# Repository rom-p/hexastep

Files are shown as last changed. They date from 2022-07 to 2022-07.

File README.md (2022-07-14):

6-axis stepper driver for **Raspberry Pi Pico**

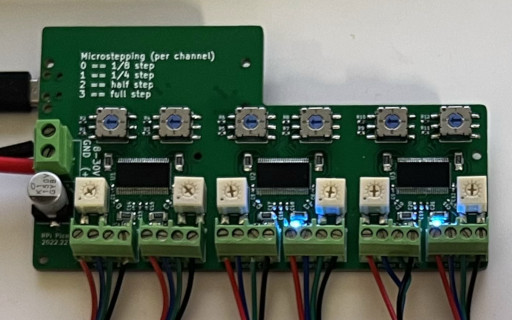
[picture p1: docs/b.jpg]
view


The **Raspberry Pi Pico** is on the back side of this board

# Prerequisites
* KiCad 6.0+
* load symbols and footprints.  The schematic and PCB depend on the library located in `/libs`, which needs to be added before opening the schematics/pcb in KiCad:
  * symbols: **KiCad** -> **Preferences** -> **Manage Symbol Libraries...**,
  * footprints: **KiCad** -> **Preferences** -> **Manage Footprint Libraries...**
* PCB manufacturing: any manufacturer capable of 4-layer and 0.4mm vias -- pretty much any PCB shop

# Schematic
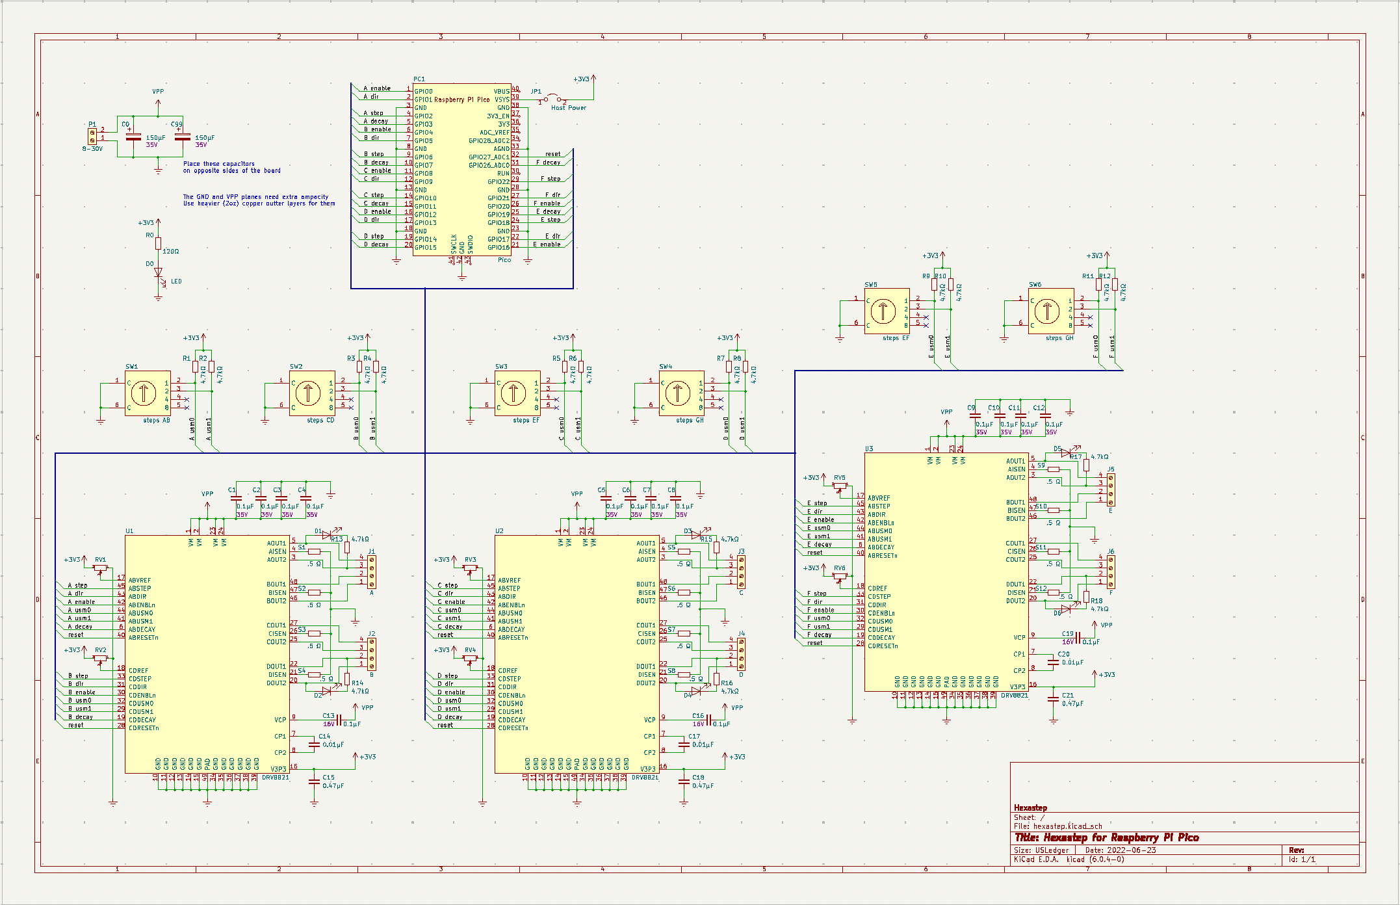
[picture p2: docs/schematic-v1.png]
schematic
  (also in [PDF](docs/schematic-v1.pdf))

# Parts
https://octopart.com/bom-tool/PoB5E81H

# Footnotes
the photo at the top of this page is of a previous version of the board.  The current version has:
  * a slightly different layout
  * a power LED
  * a jumper for powering R-Pi Pico
  * better filtering.

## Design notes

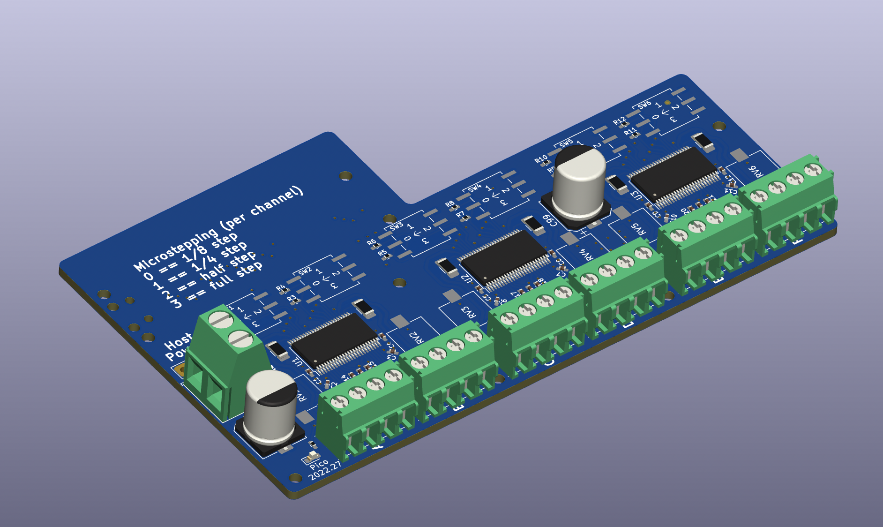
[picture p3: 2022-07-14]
docs/kicad-board-view-v1.png

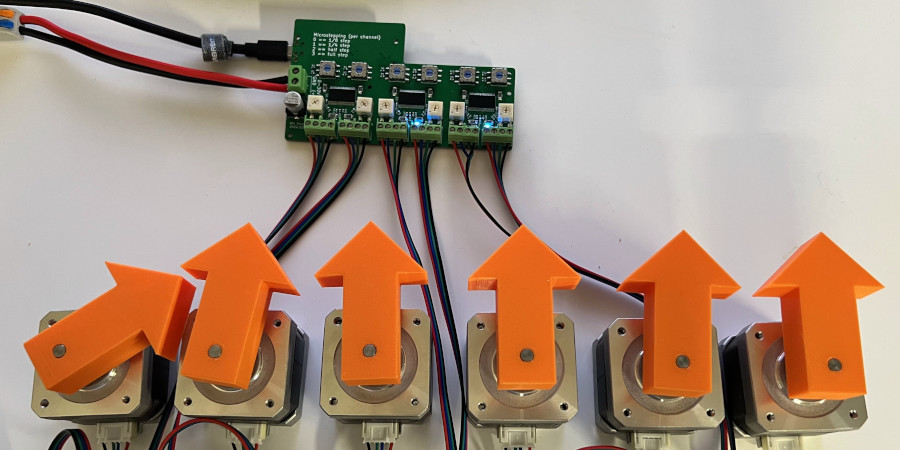
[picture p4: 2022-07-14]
docs/m.jpg

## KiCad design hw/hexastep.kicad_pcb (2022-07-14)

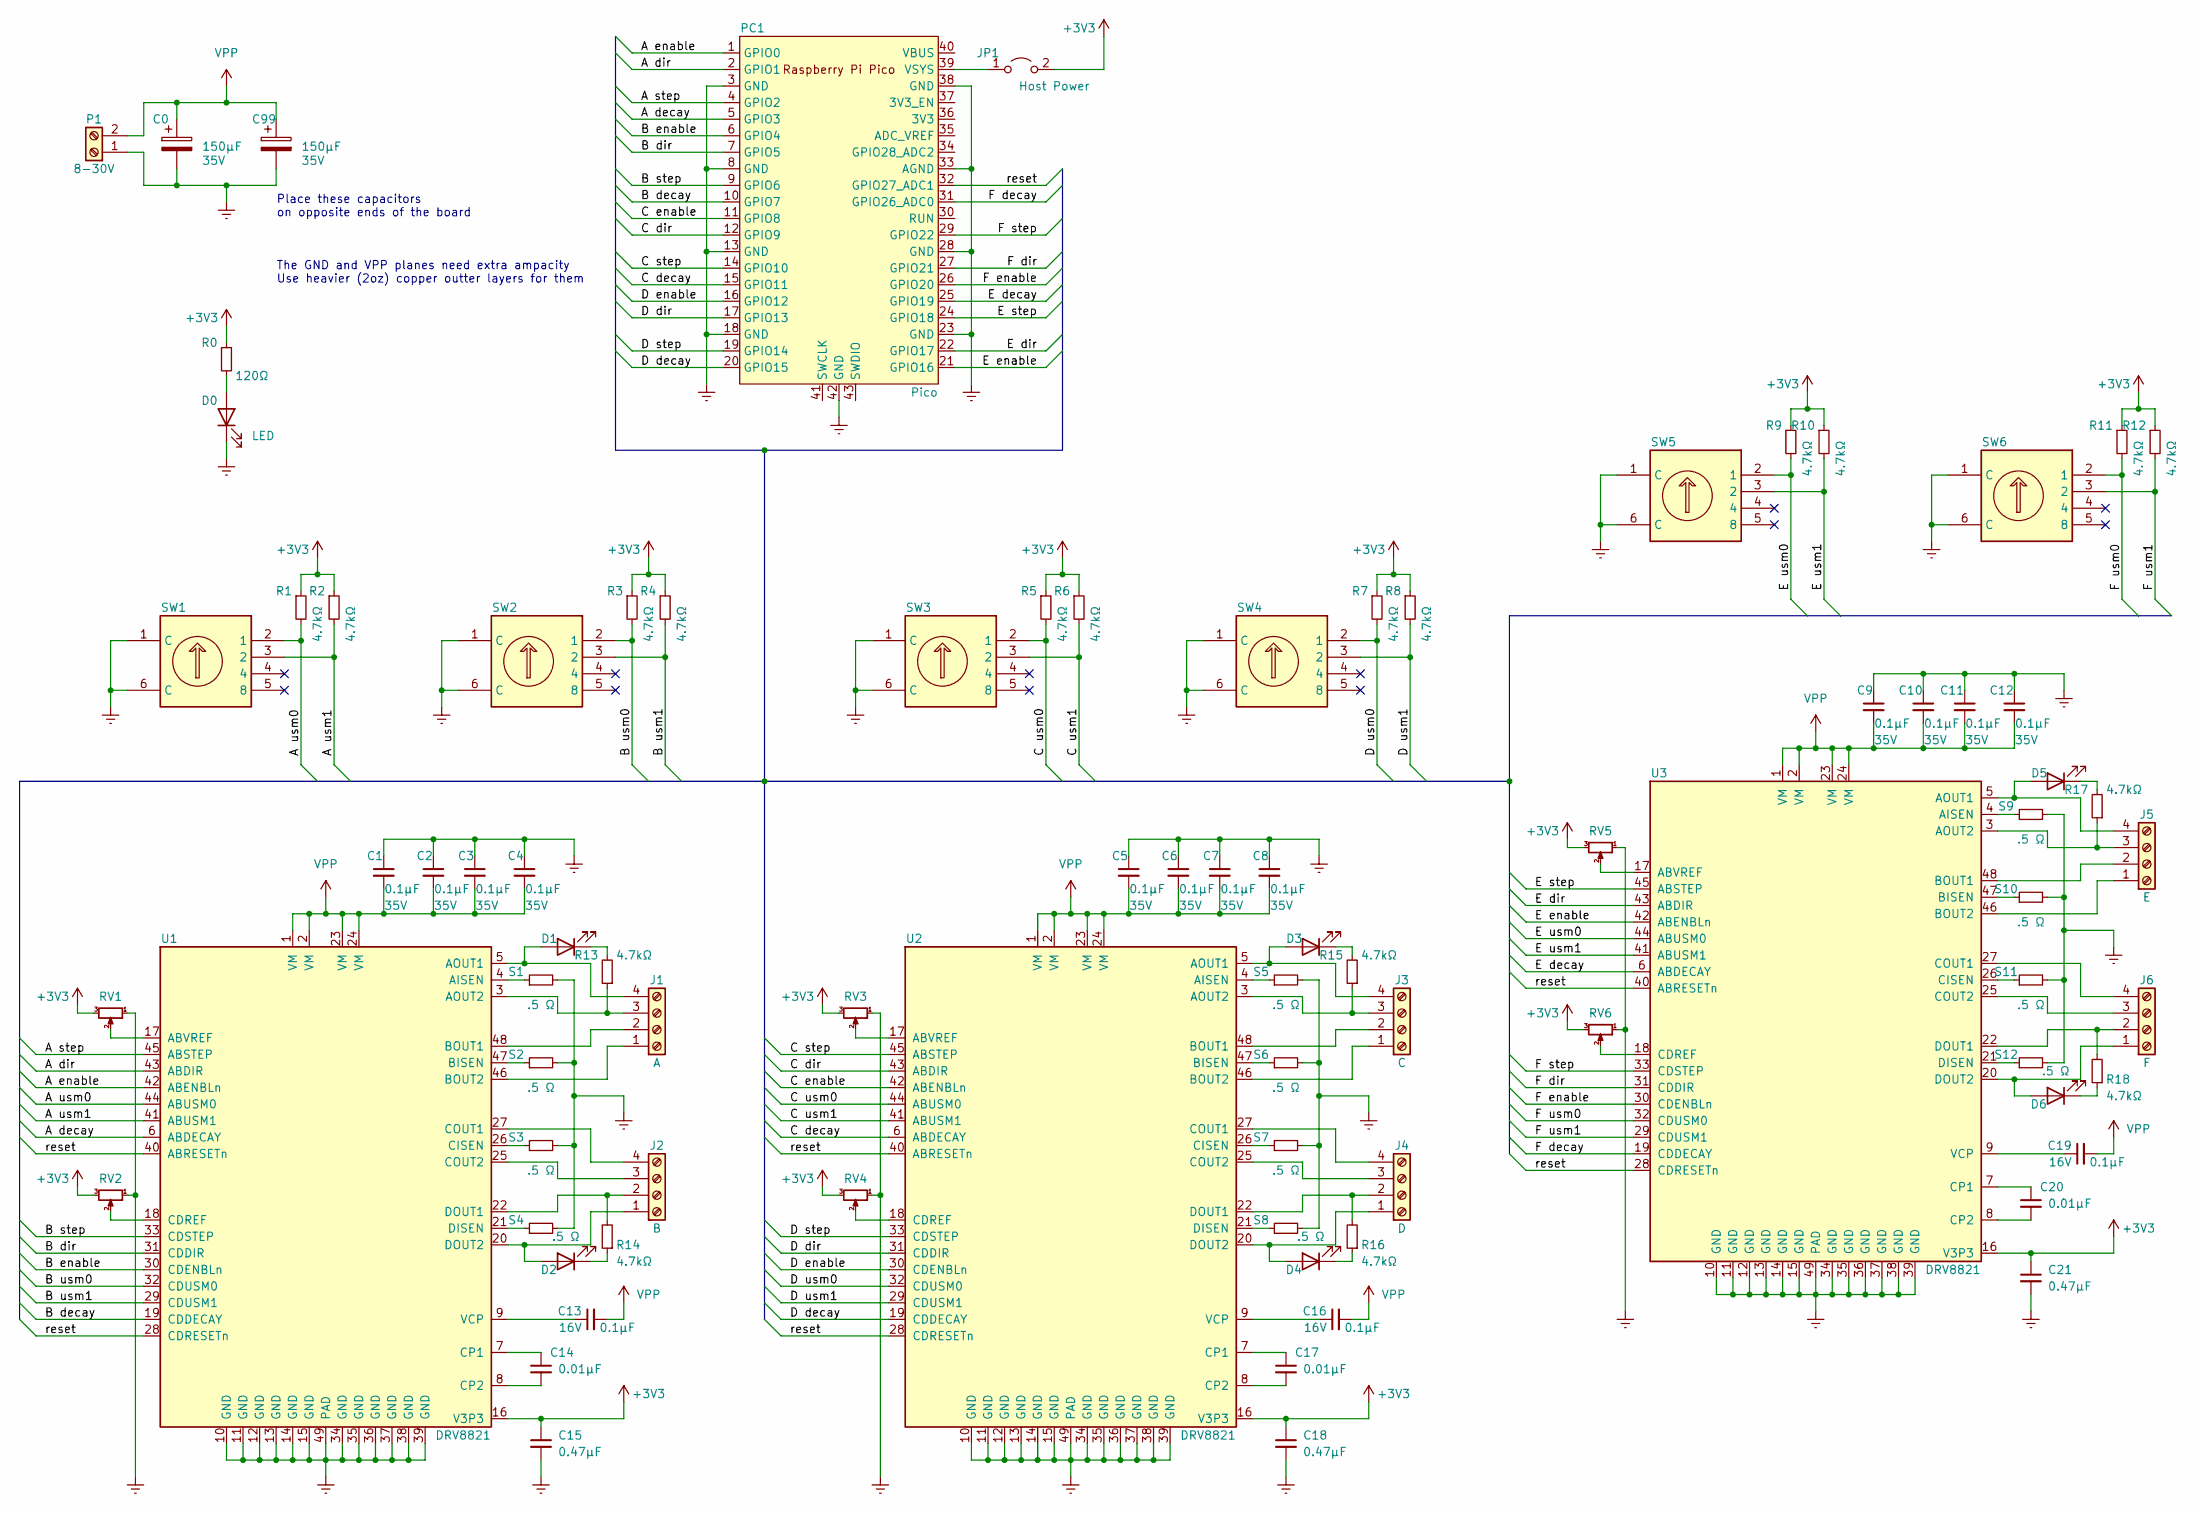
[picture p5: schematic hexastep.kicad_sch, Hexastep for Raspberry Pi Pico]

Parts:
C0, C99: 150µF; CP_Elec_8x10; Voltage 35V
C1, C2, C3, C4, C5, C6, C7, C8, C9, C10, C11, C12: 0.1µF; C_0402_1005Metric_Pad0.74x0.62mm_HandSolder; Voltage 35V
C13, C16, C19: 0.1µF; C_0402_1005Metric_Pad0.74x0.62mm_HandSolder; Voltage 16V
C14, C17, C20: 0.01µF; C_0402_1005Metric_Pad0.74x0.62mm_HandSolder
C15, C18, C21: 0.47µF; C_0402_1005Metric_Pad0.74x0.62mm_HandSolder
D0, D1, D2, D3, D4, D5, D6: LED; LED_0603_1608Metric_Pad1.05x0.95mm_HandSolder
J1: A; TerminalBlock_Phoenix_PT-1,5-4-3.5-H_1x04_P3.50mm_Horizontal
J2: B; TerminalBlock_Phoenix_PT-1,5-4-3.5-H_1x04_P3.50mm_Horizontal
J3: C; TerminalBlock_Phoenix_PT-1,5-4-3.5-H_1x04_P3.50mm_Horizontal
J4: D; TerminalBlock_Phoenix_PT-1,5-4-3.5-H_1x04_P3.50mm_Horizontal
J5: E; TerminalBlock_Phoenix_PT-1,5-4-3.5-H_1x04_P3.50mm_Horizontal
J6: F; TerminalBlock_Phoenix_PT-1,5-4-3.5-H_1x04_P3.50mm_Horizontal
JP1: Host Power; TestPoint_2Pads_Pitch5.08mm_Drill1.3mm
P1: 8-30V; TerminalBlock_Phoenix_MKDS-1,5-2-5.08_1x02_P5.08mm_Horizont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
PC1: Pico; RPi_Pico_SMD_only
R0: 120Ω; R_0402_1005Metric_Pad0.72x0.64mm_HandSolder
R1, R2, R3, R4, R5, R6, R7, R8, R9, R10, R11, R12, R13, R14, R15, R16, R17, R18: 4.7kΩ; R_0402_1005Metric_Pad0.72x0.64mm_HandSolder
RV1, RV2, RV3, RV4, RV5, RV6: R_Potentiometer_Small; Potentiometer_ACP_CA6-VSMD_Vertical
S1, S2, S3, S4, S5, S6, S7, S8, S9, S10, S11, S12: .5 Ω; R_1206_3216Metric_Pad1.30x1.75mm_HandSolder
SW1, SW2, SW3, SW4, SW5, SW6: (no value)
U1, U2, U3: DRV8821; HTSSOP-48_6.1x12.5mm_P0.5mm

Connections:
+3V3: C15.1, C18.1, C21.1, JP1.2 (B), R0.1, R1.1, R2.1, R3.1, R4.1, R5.1, R6.1, R7.1, R8.1, R9.1, R10.1, R11.1, R12.1, RV1.3, RV2.3, RV3.3, RV4.3, RV5.3, RV6.3, U1.16 (V3P3), U2.16 (V3P3), U3.16 (V3P3)
/A decay: PC1.5 (GPIO3), U1.6 (ABDECAY)
/A dir: PC1.2 (GPIO1), U1.43 (ABDIR)
/A enable: PC1.1 (GPIO0), U1.42 (ABENBLn)
/A step: PC1.4 (GPIO2), U1.45 (ABSTEP)
/A usm0: R1.2, SW1.2 (1), U1.44 (ABUSM0)
/A usm1: R2.2, SW1.3 (2), U1.41 (ABUSM1)
/B decay: PC1.10 (GPIO7), U1.19 (CDDECAY)
/B dir: PC1.7 (GPIO5), U1.31 (CDDIR)
/B enable: PC1.6 (GPIO4), U1.30 (CDENBLn)
/B step: PC1.9 (GPIO6), U1.33 (CDSTEP)
/B usm0: R3.2, SW2.2 (1), U1.32 (CDUSM0)
/B usm1: R4.2, SW2.3 (2), U1.29 (CDUSM1)
/C decay: PC1.15 (GPIO11), U2.6 (ABDECAY)
/C dir: PC1.12 (GPIO9), U2.43 (ABDIR)
/C enable: PC1.11 (GPIO8), U2.42 (ABENBLn)
/C step: PC1.14 (GPIO10), U2.45 (ABSTEP)
/C usm0: R5.2, SW3.2 (1), U2.44 (ABUSM0)
/C usm1: R6.2, SW3.3 (2), U2.41 (ABUSM1)
/D decay: PC1.20 (GPIO15), U2.19 (CDDECAY)
/D dir: PC1.17 (GPIO13), U2.31 (CDDIR)
/D enable: PC1.16 (GPIO12), U2.30 (CDENBLn)
/D step: PC1.19 (GPIO14), U2.33 (CDSTEP)
/D usm0: R7.2, SW4.2 (1), U2.32 (CDUSM0)
/D usm1: R8.2, SW4.3 (2), U2.29 (CDUSM1)
/E decay: PC1.25 (GPIO19), U3.6 (ABDECAY)
/E dir: PC1.22 (GPIO17), U3.43 (ABDIR)
/E enable: PC1.21 (GPIO16), U3.42 (ABENBLn)
/E step: PC1.24 (GPIO18), U3.45 (ABSTEP)
/E usm0: R9.2, SW5.2 (1), U3.44 (ABUSM0)
/E usm1: R10.2, SW5.3 (2), U3.41 (ABUSM1)
/F decay: PC1.31 (GPIO26_ADC0), U3.19 (CDDECAY)
/F dir: PC1.27 (GPIO21), U3.31 (CDDIR)
/F enable: PC1.26 (GPIO20), U3.30 (CDENBLn)
/F step: PC1.29 (GPIO22), U3.33 (CDSTEP)
/F usm0: R11.2, SW6.2 (1), U3.32 (CDUSM0)
/F usm1: R12.2, SW6.3 (2), U3.29 (CDUSM1)
/reset: PC1.32 (GPIO27_ADC1), U1.28 (CDRESETn), U1.40 (ABRESETn), U2.28 (CDRESETn), U2.40 (ABRESETn), U3.28 (CDRESETn), U3.40 (ABRESETn)
Earth: C0.2, C1.1, C2.1, C3.1, C4.1, C5.1, C6.1, C7.1, C8.1, C9.1, C10.1, C11.1, C12.1, C15.2, C18.2, C21.2, C99.2, D0.1 (K), P1.1, PC1.3 (GND), PC1.8 (GND), PC1.13 (GND), PC1.18 (GND), PC1.23 (GND), PC1.28 (GND), PC1.33 (AGND), PC1.38 (GND), PC1.42 (GND), RV1.1, RV2.1, RV3.1, RV4.1, RV5.1, RV6.1, S1.2, S2.2, S3.2, S4.2, S5.2, S6.2, S7.2, S8.2, S9.2, S10.2, S11.2, S12.2, SW1.1 (C), SW1.6 (C), SW2.1 (C), SW2.6 (C), SW3.1 (C), SW3.6 (C), SW4.1 (C), SW4.6 (C), SW5.1 (C), SW5.6 (C), SW6.1 (C), SW6.6 (C), U1.10 (GND), U1.11 (GND), U1.12 (GND), U1.13 (GND), U1.14 (GND), U1.15 (GND), U1.34 (GND), U1.35 (GND), U1.36 (GND), U1.37 (GND), U1.38 (GND), U1.39 (GND), U1.49 (PAD), U2.10 (GND), U2.11 (GND), U2.12 (GND), U2.13 (GND), U2.14 (GND), U2.15 (GND), U2.34 (GND), U2.35 (GND), U2.36 (GND), U2.37 (GND), U2.38 (GND), U2.39 (GND), U2.49 (PAD), U3.10 (GND), U3.11 (GND), U3.12 (GND), U3.13 (GND), U3.14 (GND), U3.15 (GND), U3.34 (GND), U3.35 (GND), U3.36 (GND), U3.37 (GND), U3.38 (GND), U3.39 (GND), U3.49 (PAD); also elsewhere on the board
unnamed: C13.1, U1.9 (VCP)
unnamed: C14.1, U1.7 (CP1)
unnamed: C14.2, U1.8 (CP2)
unnamed: C16.1, U2.9 (VCP)
unnamed: C17.1, U2.7 (CP1)
unnamed: C17.2, U2.8 (CP2)
unnamed: C19.1, U3.9 (VCP)
unnamed: C20.1, U3.7 (CP1)
unnamed: C20.2, U3.8 (CP2)
unnamed: D0.2 (A), R0.2
unnamed: D1.1 (K), R13.2
unnamed: D1.2 (A), J1.4, U1.5 (AOUT1)
unnamed: D2.1 (K), R14.1
unnamed: D2.2 (A), J2.1, U1.20 (DOUT2)
unnamed: D3.1 (K), R15.2
unnamed: D3.2 (A), J3.4, U2.5 (AOUT1)
unnamed: D4.1 (K), R16.1
unnamed: D4.2 (A), J4.1, U2.20 (DOUT2)
unnamed: D5.1 (K), R17.2
unnamed: D5.2 (A), J5.4, U3.5 (AOUT1)
unnamed: D6.1 (K), R18.1
unnamed: D6.2 (A), J6.1, U3.20 (DOUT2)
unnamed: J1.1, U1.46 (BOUT2)
unnamed: J1.2, U1.48 (BOUT1)
unnamed: J1.3, R13.1, U1.3 (AOUT2)
unnamed: J2.2, R14.2, U1.22 (DOUT1)
unnamed: J2.3, U1.25 (COUT2)
unnamed: J2.4, U1.27 (COUT1)
unnamed: J3.2, U2.48 (BOUT1)
unnamed: J3.3, R15.1, U2.3 (AOUT2)
unnamed: J4.2, R16.2, U2.22 (DOUT1)
unnamed: J4.3, U2.25 (COUT2)
unnamed: J4.4, U2.27 (COUT1)
unnamed: J5.2, U3.48 (BOUT1)
unnamed: J5.3, R17.1, U3.3 (AOUT2)
unnamed: J6.2, R18.2, U3.22 (DOUT1)
unnamed: J6.3, U3.25 (COUT2)
unnamed: J6.4, U3.27 (COUT1)
unnamed: JP1.1 (A), PC1.39 (VSYS)
unnamed: RV1.2, U1.17 (ABVREF)
unnamed: RV2.2, U1.18 (CDREF)
unnamed: RV3.2, U2.17 (ABVREF)
unnamed: RV4.2, U2.18 (CDREF)
unnamed: RV5.2, U3.17 (ABVREF)
unnamed: RV6.2, U3.18 (CDREF)
unnamed: S1.1, U1.4 (AISEN)
unnamed: S2.1, U1.47 (BISEN)
unnamed: S3.1, U1.26 (CISEN)
unnamed: S4.1, U1.21 (DISEN)
unnamed: S5.1, U2.4 (AISEN)
unnamed: S6.1, U2.47 (BISEN)
unnamed: S7.1, U2.26 (CISEN)
unnamed: S8.1, U2.21 (DISEN)
unnamed: S9.1, U3.4 (AISEN)
unnamed 93: S10.1, U3.47 (BISEN); also elsewhere on the board
unnamed 94: S11.1, U3.26 (CISEN); also elsewhere on the board
unnamed 95: S12.1, U3.21 (DISEN); also elsewhere on the board
unnamed: J3.1, U2.46 (BOUT2)
unnamed: J5.1, U3.46 (BOUT2)
VPP: C0.1, C1.2, C2.2, C3.2, C4.2, C5.2, C6.2, C7.2, C8.2, C9.2, C10.2, C11.2, C12.2, C13.2, C16.2, C19.2, C99.1, P1.2, U1.1 (VM), U1.2 (VM), U1.23 (VM), U1.24 (VM), U2.1 (VM), U2.2 (VM), U2.23 (VM), U2.24 (VM), U3.1 (VM), U3.2 (VM), U3.23 (VM), U3.24 (VM)

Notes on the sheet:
Place these capacitors on opposite ends of the board
The GND and VPP planes need extra ampacity Use heavier (2oz) copper outter layers for them

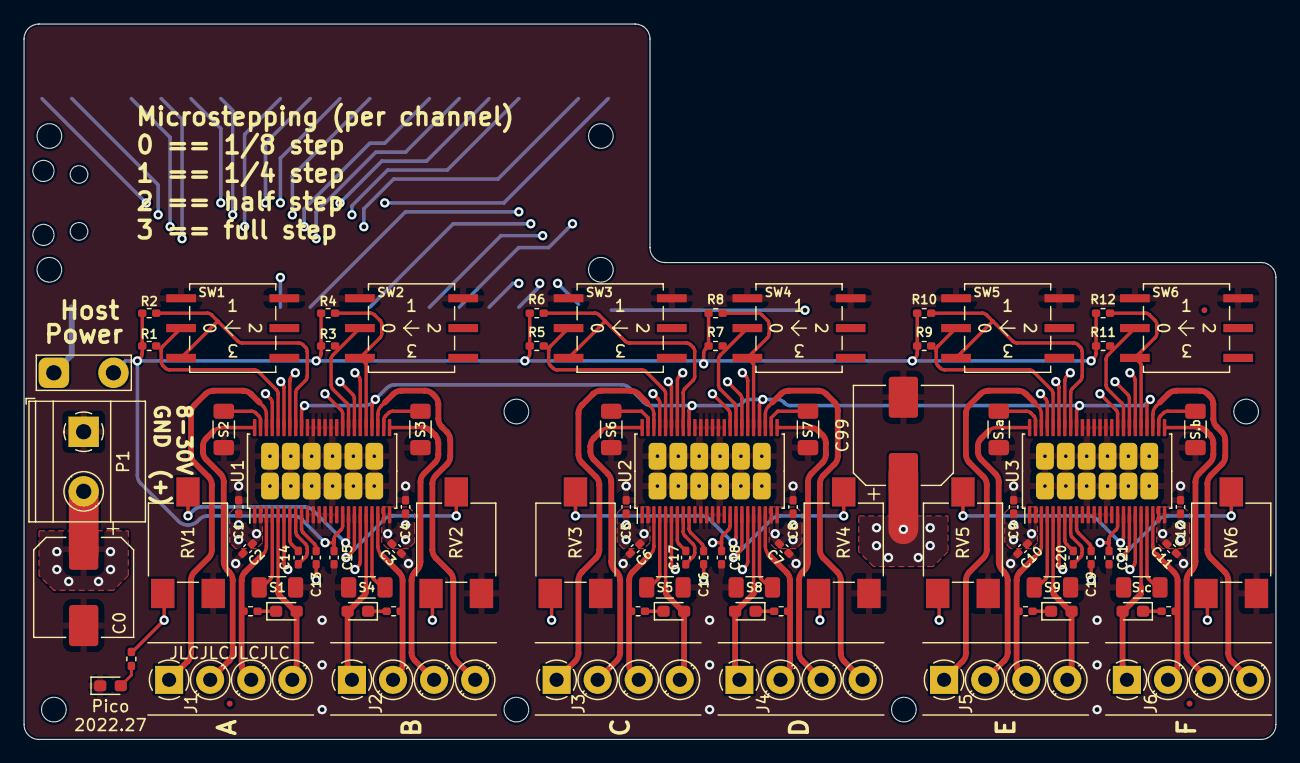
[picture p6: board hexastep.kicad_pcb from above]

Board: 4 copper layers, 106.7 x 61.0 mm, 85 parts (1 on the bottom side), 99 nets.

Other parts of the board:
S.a, S.b, S.c: .5 Ω; R_1206_3216Metric_Pad1.30x1.75mm_HandSolder

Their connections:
Earth: S.a.2, S.b.2, S.c.2; also elsewhere on the board
unnamed 93: S.a.1; also elsewhere on the board
unnamed 94: S.b.1; also elsewhere on the board
unnamed 95: S.c.1; also elsewhere on the board
